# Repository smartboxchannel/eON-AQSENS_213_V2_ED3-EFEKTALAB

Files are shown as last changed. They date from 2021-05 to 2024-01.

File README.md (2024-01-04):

# EFEKTA-EINK213-AIR-QUALITY-SENSOR-NRF52840-V2-ED3

Wireless, battery-operated Mini air quality and weather station. Air quality, temperature, humidity, pressure, weather forecast. Designed on the nRF52833, nRF52840 wireless radio modules. The temperature, humidity and pressure sensor BME280, air quality sensor SGP40 is used The device is powered by CR2477 battery. Consumption when transmitting data is 8mA, in sleep mode is 35uA (see datasheet SGP40).

Телеграм чат DIY Devices - https://t.me/diy_devices

Продажа DIY Устройств - https://t.me/diydevmart

### You can buy a ready-made device by writing to the mail hello@efektalab.com

### Delivery is carried out worldwide.

### You can make your own pcb here - https://www.pcbway.com/setinvite.aspx?inviteid=550959

https://hackaday.io/project/180248-eon-indoor-air-quality-sensor
---

#### GDEH0213B72 (GDEH0213B73, Waveshare V2): https://ali.ski/05GbQ

(250x122,2.13inch E-Ink raw display panel Without PCB Communicate via SPI interface)

#### MS88SF3: https://ali.ski/I_UNg

(New FCC CE RoHs Certificated Compact (18.5×12.5×2mm) and Flexible ultra-low power wireless BLE 5.0 Module based on nRF52840 SoCs)

#### SGP40: https://ali.ski/3sbUP  |  https://ali.ski/9caWj

Video: 

More info at http://efektalab.com/eink213_ed3

---
## Ver. A

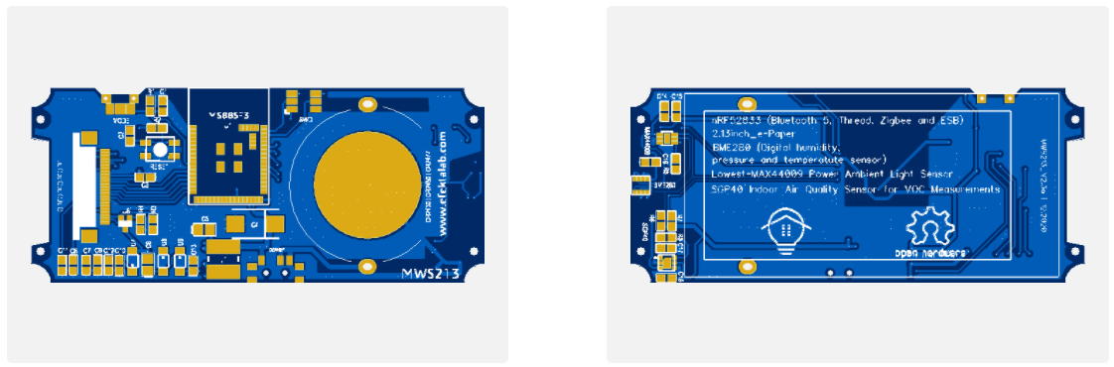
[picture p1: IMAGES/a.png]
 

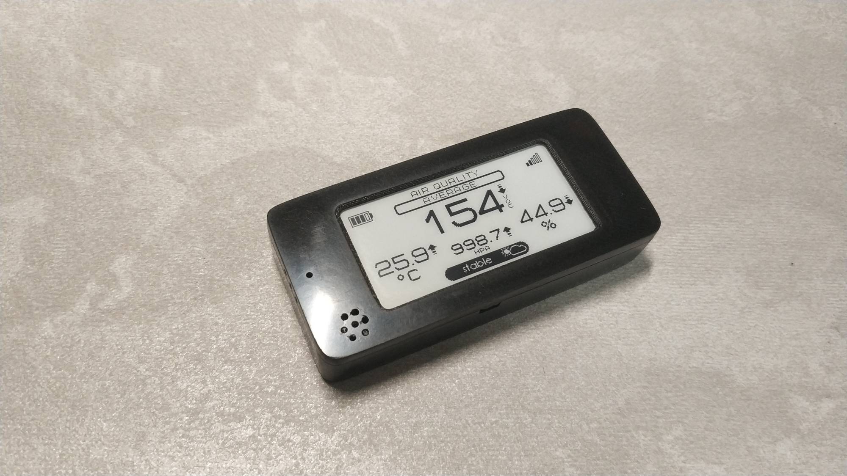
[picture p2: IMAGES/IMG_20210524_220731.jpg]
 

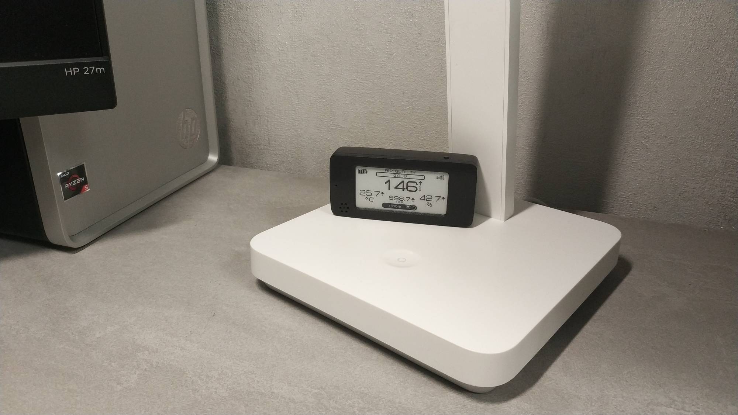
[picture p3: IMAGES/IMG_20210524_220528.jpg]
 

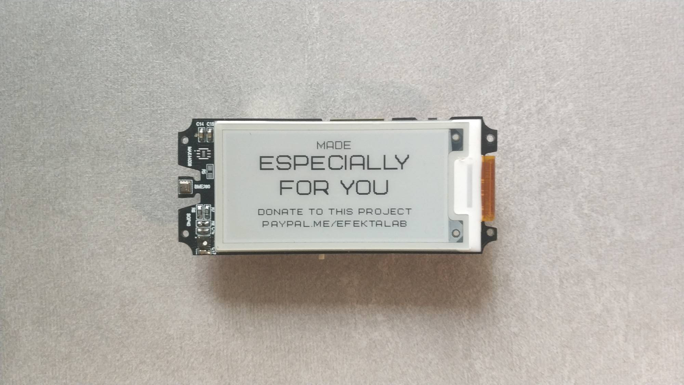
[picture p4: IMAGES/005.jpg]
 

---

EFEKTA EINK102 TEMP HUM MICRO SENSOR NRF52 licenses

---

### Instruction

#### First of all, I recommend installing the Arduino IDE portable (optional, but desirable)

https://www.arduino.cc/en/Guide/PortableIDE

#### 1. Install the latest arduino-nRF5 library (https://github.com/sandeepmistry/arduino-nRF5)

#### 2. Install the latest version of the MySensors library (https://github.com/mysensors/MySensors)

#### 3. Download the archive of this project to your computer

#### 4. Add support for devices of this project to the arduino-nRF5 library, the description is in the README.md file (https://github.com/smartboxchannel/EFEKTA-EINK213-TEMP-HUM-PRESS-SENSOR-NRF52840-V2/tree/master/for_sandeepmistry_nRF5/README.md)

#### 5. Add support for interrupts via gpiote, for this go to the ... packages \ sandeepmistry \ hardware \ nRF5 \ 0.7.0 \ cores \ nRF5 folder, and in the WInterrupts.c file, before the void GPIOTE_IRQHandler () function, add the line: \_\_attribute\_\_ ((weak ))

#### 6. Add the libraries in the archive () https://github.com/smartboxchannel/EFEKTA-EINK213-TEMP-HUM-PRESS-SENSOR-NRF52840-V2/tree/master/CODE/Arduino/libraries  of this project to the libraries folder on your computer ( path: ...\Documents\Arduino\libraries )

#### 7. Create an EINK213ED2 folder on your computer under the Arduino directory (Documents \ Arduino). Add the files of this project located in the Arduino section (https://github.com/smartboxchannel/EFEKTA-EINK213-TEMP-HUM-PRESS-SENSOR-NRF52840-V2/tree/master/CODE/Arduino) to the created EINK213ED2 folder

#### 8. Open the EINK213ED2.ino file in the Arduino IDE program, go to the aConfig.h tab and configure according to your board version and settings of your MySensors network.

#### 9. In the main menu of the Arduino IDE go to Tools-> Boards-> Nordic Semiconductors nRF5 Boards, in the list that opens, select the EFEKTA MWS213 V2 nRF52840 board. In the menu of the selected board, select the type of clock crystal (external), also select the Reset: Enable item.

#### 10. Click on the icon - check and then download

---

---

## Components (BOM):

SGP40: https://ali.ski/eZQog

MINEW MS88SF3 FCC CE RoHs Certificated wireless module nRF52840 SoCs - https://ali.ski/9LnWZ (1 pc - $7.75)

MAX44009EDT  - https://ali.ski/_PLrJ  (5 pcs - $9.3)
OR
MAX44009EDT  - https://ali.ski/bZoMnn  (1 pc - $1.9)

BME280 - https://ali.ski/wLEIir (2 pcs - $11.5)

Waveshare 250x122 2,13 - https://ali.ski/D4eOVU (1pc - $12.3)

FPC FFC 0.5mm connector socket 24 pin - https://ali.ski/lCBot0 (1 p - $0.77)

Cell Holder CR2450 - https://ali.ski/VdotsA (20 pcs - $3)

Micro Screws M1.4 3mm - https://ali.ski/gaFdO (100 pcs - $1)

Micro Screws M1.4 5mm - https://ali.ski/gaFdO (100 pcs - $1)

Micro SMD Tact Switch 2x4 2*4*3.5 - https://ali.ski/_D78Q (10 pcs - $1)

Neodymium magnet 15x3x3m - https://ali.ski/44p3R (10 pcs - $7)

Tantalum Capacitor 100UF 10V - https://ali.ski/Lx9iQd (10 pcs - $1,85)

Inductor Power Shielded Wirewound NR5040 5x5x4mm - https://ali.ski/iblu8q (50 pcs - $3)

Micro Button Tact Switch SMD 4Pin 3X4X2.5 - https://ali.ski/sGwFu (100 pcs - $1.7)

SMD Mini Toggle Slide Switch 7-Pin On/Off - https://ali.ski/xz9Yt (100 pcs - $3.2)

SI1308EDL - https://ali.ski/Q6Y12 (20 pcs - $5.3)
OR
Si1304BDL - https://ali.ski/938Klh (100 pcs - $15.5)

SMD Chip Multilayer Ceramic Capacitor 0603 1UF 25V - https://ali.ski/p3yr60 (100 pcs - $1.5)

SMD Chip Multilayer Ceramic Capacitor 0603 0.1UF 50V - https://ali.ski/p3yr60 (100 pcs - $1.5)

SMD Chip Multilayer Ceramic Capacitor 0805 4.7UF - https://ali.ski/iFXAc (100 pcs - $1.85)

MBR0530T1G - https://ali.ski/SJM7aK (100 pcs - $1.1)

SMD LED 0805 - https://ali.ski/wb6ZP (100 pcs - $2)

1% SMD resistor 0.47R 0603 - https://ali.ski/bX9HUg (100 pcs - $1.2)

1% SMD Resistor Kit Assorted Kit 1R-1M 0603 -  https://ali.ski/npItF (660 pcs - $1.45)

SUNLU PLA Carbon Fiber Premium 3D Printer Filament - https://ali.ski/bQkNR (1 pcs - $26.5)

405nm UV Resin For 3d Printer - https://ali.ski/sW0MUm (1 pcs - $18.5)

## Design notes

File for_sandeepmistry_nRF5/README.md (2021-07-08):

#### 1. Add lines from the file boards.txt to a file with the same name(boards.txt) located in the installed 'sandeepmistry' library. 

Path: ...\AppData\Local\Arduino15\packages\sandeepmistry\hardware\nRF5\0.7.0

#### 2. Replace the file platform.txt with a similar file from this repository 

Path: ...\AppData\Local\Arduino15\packages\sandeepmistry\hardware\nRF5\0.7.0

#### 3. Add the folder EFEKTA_MWS213_V2 with all the attached files to the /variants folder

Path: ...\AppData\Local\Arduino15\packages\sandeepmistry\hardware\nRF5\0.7.0\variants

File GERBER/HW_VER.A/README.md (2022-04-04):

Нou can make your own pcb here - https://www.pcbway.com/setinvite.aspx?inviteid=550959

pcb 1mm - https://www.pcbway.com/project/shareproject/eON_AQSENS_213_dab8c1e9.html

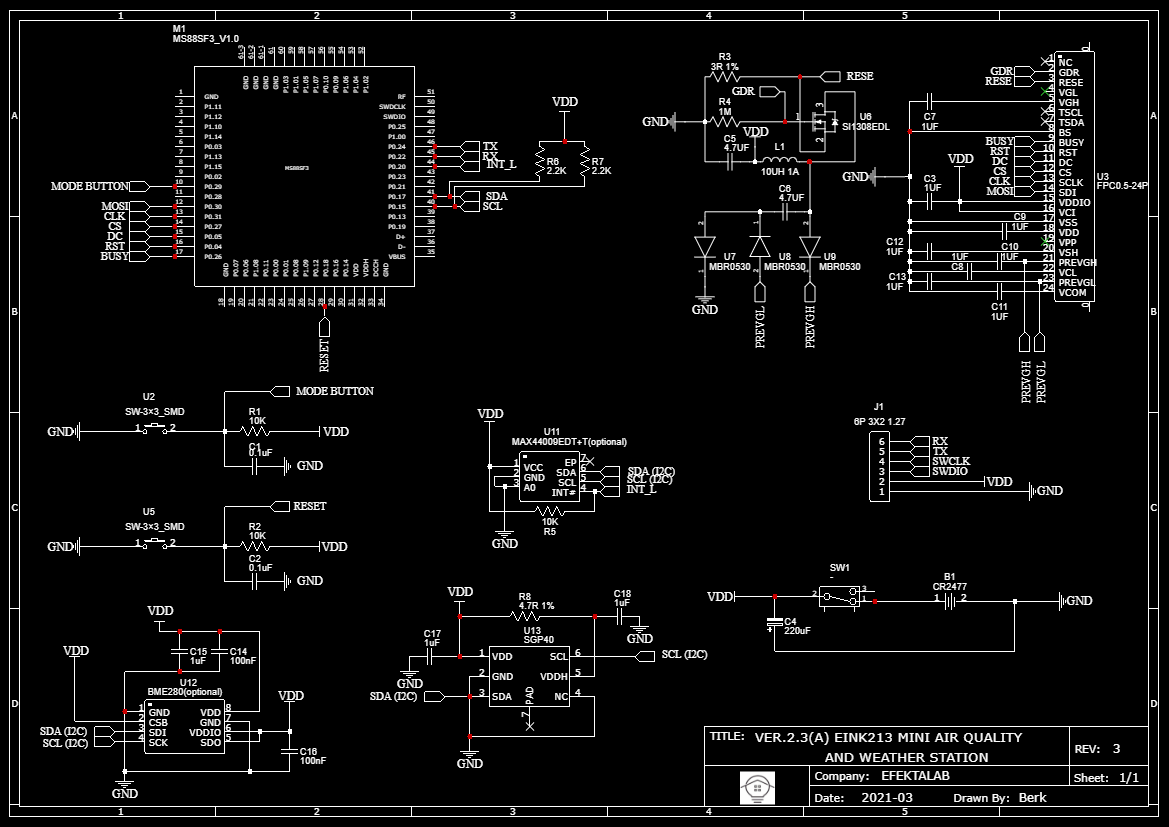
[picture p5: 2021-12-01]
SCHEME/aq_V2.3a _12.2020.png

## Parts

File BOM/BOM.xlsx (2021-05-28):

Comment | Designator | Footprint
100nF | C1,C2,C14,C15 | 0603_C | https://ali.ski/p3yr60
1uF | C3,C7,C8,C9,C10,C11,C12,C13,C15,C17,C18 | 0603_C | https://ali.ski/p3yr60
100uF | C4 | D_Tantal | https://ali.ski/Lx9iQd
4.7uF | C5,C6 | C0805 | https://ali.ski/iFXAc
6P | J1 | 6x1.27 | https://ali.ski/j2fO8
10uH\1A | L1 | CD54 | https://ali.ski/iblu8q
10KΩ | R1,R2,R5 | 0603_R | https://ali.ski/bX9HUg
3Ω\1% | R3 | 0603_R | https://ali.ski/bX9HUg
1MΩ | R4 | 0603_R | https://ali.ski/bX9HUg
2.2KΩ | R6,R7 | 0603_C | https://ali.ski/bX9HUg
4.7Ω\1% | R8 | 0603_R | https://ali.ski/bX9HUg
MS88SF3\MINEW | U1 | MS88SF3 | https://ali.ski/9LnWZ
BUTTON | U2 | but 2x4 2*4*3,5 | https://ali.ski/_D78Q
BAT HOLDER | U3 | CR2477 | https://ali.ski/VdotsA
FPC24 | U4 | FPC24 | https://ali.ski/lCBot0
BUTTON | U5 | B_3X4X2,5 | https://ali.ski/sGwFu
SI1308EDL | U6 | SC70 | https://ali.ski/Q6Y12
MBR0530 | U7,U8,U9 | SOD-123 | https://ali.ski/SJM7aK
POWER SWITCH | U10 | dsc0012 | https://ali.ski/xz9Yt
MAX44009 | U11 | 6 UTDFN-Opto | https://ali.ski/_PLr (https://ali.ski/_PLrJ)
BME280 | U12 | LGA | https://ali.ski/wLEIir
SGP40 | U13 | 6-pin DFN | https://ali.ski/eZQog
 | Waveshare 250x122 2,13 - https://ali.ski/D4eOVU
 | Micro Screws M1.4 3mm - https://ali.ski/gaFdO
 | Micro Screws M1.4 5mm - https://ali.ski/gaFdO
 | Neodymium magnet 15x3x3m - https://ali.ski/44p3R

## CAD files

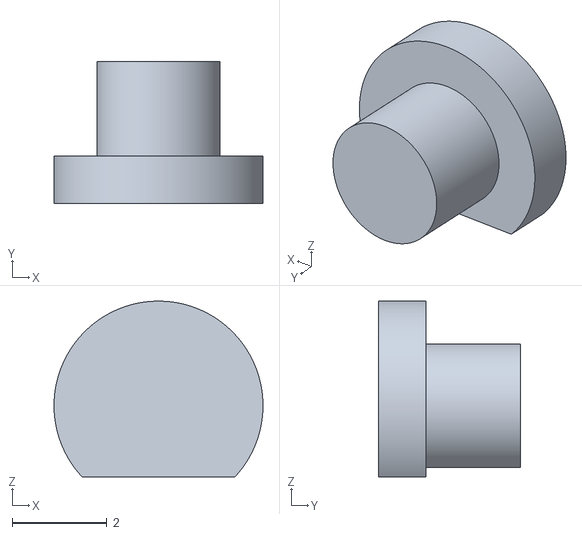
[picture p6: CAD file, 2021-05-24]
CASE 3D MODELS/BUTTON.STL
4.40 x 3.00 x 3.70

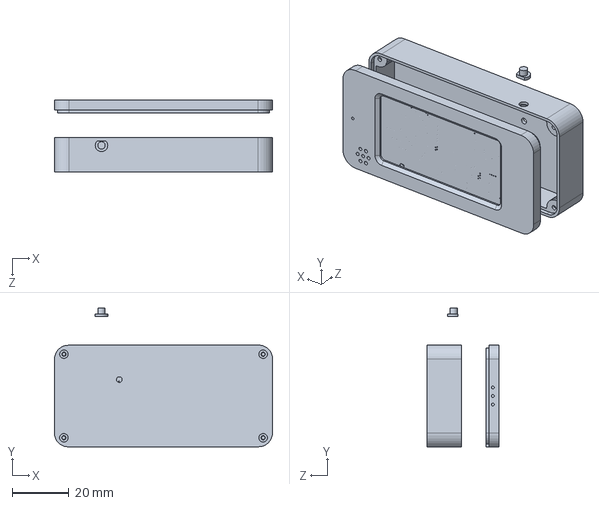
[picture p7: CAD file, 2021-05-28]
CASE 3D MODELS/SOURCE/AQ.SLDPRT
76.6 x 48.7 x 25.4 mm

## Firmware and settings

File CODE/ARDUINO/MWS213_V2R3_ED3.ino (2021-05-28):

// ###################   Mini air quality and wither station with electronic ink display 2.13 Inch | nRF52   ############### //
//                                                                                                                           //
//        @filename   :   MWS213_V2R3_ED3.ino                                                                                //
//        @brief en   :   Wireless, battery-operated air quality(VOC Sensor SGP40), temperature,humidity and pressure        //
//                        sensor(BME280) with electronic ink display(Good Display GDEH0213B72, GDEH0213B73, Waveshare V2).   //
//                        Works on SOC nRF52.                                                                                //
//        @brief ru   :   Беcпроводной, батарейный датчик качества воздуха (ЛОС сенсорс SGP40), температуры, влажности       //
//                        и давления(BME280) с дисплеем на электронных чернилах(Good Display GDEH0213B72, GDEH0213B73,       //
//                        Waveshare V2).                                                                                     //
//                        Работает на nRF52832, nRF52840.                                                                    //
//                                                                                                                           //
//        @author     :   Andrew Lamchenko aka Berk                                                                          //
//                                                                                                                           //
//        Copyright (C) 2021, EFEKTALAB                                                                                      //
//        Copyright (c) 2020, Sensirion AG                                                                                   //
//        Copyright (c) 2020, Bosch Sensortec GmbH. All rights reserved.                                                     //
//        Copyright (c) 2014-2015, Arduino LLC.  All right reserved.                                                         //
//        Copyright (c) 2016, Arduino Srl.  All right reserved.                                                              //
//        Copyright (c) 2017, Sensnology AB. All right reserved.                                                             //
//        Copyright (C) 2020, Waveshare                                                                                      //
//                                                                                                                           //
// ######################################################################################################################### //



#include "aConfig.h" //Edit this file for your sensor configuration


// ##############################################################################################################
// #                                                 DRIVERS & LIB                                              #
// ##############################################################################################################
#include "eink213_V2.h"
#include "imagedata.h"
#include "einkpaint.h"
#include "Adafruit_SGP40.h" // !!!Non-standard constants are used for the air quality algorithm!!!
#include <Adafruit_Sensor.h>
#include <Adafruit_BME280.h>
// ##############################################################################################################



// ##############################################################################################################
// #                                                   VARIABLES                                                #
// ##############################################################################################################
unsigned char image[4000];
Paint paint(image, 0, 0);
Epd epd;
#define SEALEVELPRESSURE_HPA (1013.25)
Adafruit_BME280 bme;
Adafruit_SGP40 sgp;

int32_t voc_index;
int32_t old_voc_index = -500;
int32_t voc_index_Threshold = 10;
uint16_t sraw;
int32_t temp_voc_index;

float last_tmp;
bool upTemp;
bool downTemp;

float last_hm;
bool upHum;
bool downHum;

float last_pr;
bool upPress;
bool downPress;

long last_aq;
bool upAq;
bool downAq;

bool mesColorSet;
#ifdef SEND_RESET_REASON
bool mesReset;
#endif
bool mesBatSet;
bool mesAq;
bool mesVolt;
bool mesLink;
bool mesForec;
bool mesBaro;
bool mesHum;
bool mesTemp;
bool mesInfo;
bool needPresent;
bool metric;
bool colorPrint;
bool opposite_colorPrint;
bool sendAfterResTask;
bool changeB = true;
bool changeC = true;
bool updateink1;
bool updateink2;
bool updateink3;
bool updateink4;
bool updateinkclear;
bool check;
bool chek_h = true;
bool flag_update_transport_param;
bool flag_sendRoute_parent;
bool flag_no_present;
bool flag_nogateway_mode;
bool flag_find_parent_process;
bool nosleep;
bool change;
bool Ack_FP;
bool tch;
bool hch;
bool bch;
bool vch;
bool pch;
bool fch;
bool ach;
bool lch;
bool configMode;
bool button_flag;
uint8_t lang;
uint8_t cpNom;
uint8_t cpCount;
uint8_t battSend;
uint8_t timeSend = 1;
uint8_t battery;
uint8_t old_battery;
uint8_t err_delivery_beat;
const uint16_t shortWait = 5;
int16_t temperatureInt;
int16_t humidityInt;
int16_t pressureInt;
int16_t pressure_mmInt;
uint16_t batteryVoltage;
uint16_t old_batteryVoltage;
const uint16_t minuteT = 60000;
uint16_t BATT_TIME;
uint16_t BATT_COUNT;
int16_t nRFRSSI;
int16_t old_nRFRSSI = 127;
int16_t myid;
int16_t mypar;
int16_t old_mypar = -1;
float temperatureSend;
float pressureSend;
float humiditySend;
float old_temperature;
float old_humidity;
float old_pressure;
float tempThreshold = 0.5; // порог сравнения в предыдущими показаниями температуры
float humThreshold = 2.5; // порог сравнения в предыдущими показаниями влажности
float pressThreshold = 1.0; // порог сравнения в предыдущими показаниями влажности
float batteryVoltageF;

uint32_t configMillis;
uint32_t previousMillis;
uint32_t SLEEP_TIME;
uint32_t stopTimer;
uint32_t startTimer;
uint32_t PRECISION_TIME_WDT;
const uint32_t SLEEP_TIME_WDT = 3000;
uint32_t sleepTimeCount;
const uint8_t fastView = 5;
uint8_t checkFast;
// ##############################################################################################################



// ##############################################################################################################
// #                                                   MYSENSORS                                                #
// ##############################################################################################################
int16_t mtwr;
#define MY_TRANSPORT_WAIT_READY_MS (mtwr)
#include <MySensors.h>
#define TEMP_CHILD_ID 0
#define HUM_CHILD_ID 1
#define BARO_CHILD_ID 2
#define FORECAST_CHILD_ID 3
#define AQ_CHILD_ID 4
#define SIGNAL_Q_ID 100
#define BATTERY_VOLTAGE_ID 101
#define SET_BATT_SEND_ID 103
#define SET_COLOR_ID 104
#ifdef SEND_RESET_REASON
#define RESET_REASON_ID 105
#endif
MyMessage sqMsg(SIGNAL_Q_ID, V_VAR1);
MyMessage bvMsg(BATTERY_VOLTAGE_ID, V_VAR1);
// ##############################################################################################################


// ##############################################################################################################
// #                                                 FORECAST                                                   #
// ##############################################################################################################
#define CONVERSION_FACTOR (1.0/10.0)
const char *weather[] = { "stable", "sunny", "cloudy", "unstable", "thunderstorm", "unknown" };
enum FORECAST
{
  STABLE = 0,                     // "Stable Weather Pattern"
  SUNNY = 1,                      // "Slowly rising Good Weather", "Clear/Sunny "
  CLOUDY = 2,                     // "Slowly falling L-Pressure ", "Cloudy/Rain "
  UNSTABLE = 3,                   // "Quickly rising H-Press",     "Not Stable"
  THUNDERSTORM = 4,               // "Quickly falling L-Press",    "Thunderstorm"
  UNKNOWN = 5                     // "Unknown (More Time needed)
};
int16_t forecast;
int16_t  old_forecast = -1;
const int LAST_SAMPLES_COUNT = 5;
float lastPressureSamples[LAST_SAMPLES_COUNT];
int minuteCount = 0;
bool firstRound = true;
float pressureAvg;
float pressureAvg2;
float dP_dt;
// ##############################################################################################################


// ##############################################################################################################
// #                                                 INTERRUPTS                                                 #
// ##############################################################################################################
uint32_t PIN_BUTTON_MASK;
volatile byte buttIntStatus = 0;
#define APP_GPIOTE_MAX_USERS 1
extern "C" {
#include "app_gpiote.h"
#include "nrf_gpio.h"
}
static app_gpiote_user_id_t m_gpiote_user_id;
// ##############################################################################################################


void preHwInit() {
  pinMode(PIN_BUTTON, INPUT);
}

void before() {

  // ##############################################################################################################
  // #                                                   CONFIG MCU                                               #
  // ##############################################################################################################
  NRF_POWER->DCDCEN = 1;
  NRF_SAADC ->ENABLE = 0;
  NRF_PWM0  ->ENABLE = 0;
  NRF_NFCT->TASKS_DISABLE = 1;
  NRF_NVMC->CONFIG = 1;
  NRF_UICR->NFCPINS = 0;
  NRF_NVMC->CONFIG = 0;
  NRF_PWM1  ->ENABLE = 0;
  NRF_PWM2  ->ENABLE = 0;
  NRF_TWIM1 ->ENABLE = 0;
  NRF_TWIS1 ->ENABLE = 0;
#ifndef MY_DEBUG
  NRF_UART0->ENABLE = 0;
#endif


  // ##############################################################################################################
  // #                                                  INIT HAPPY MODE                                           #
  // ##############################################################################################################
  happy_init();


  // ##############################################################################################################
  // #                                                    CONFIG PROG                                             #
  // ##############################################################################################################
  battSend = loadState(103);  // Saving in memory the interval of sending data about battery charge and signal quality,
  // maximized 24 hours, if 0, the sending does not do, only updates the info on the screen
  if (battSend > 24) {
    battSend = 6;
    saveState(103, battSend);
  }
  //battSend = 1; // for the test, 1 hour

  if (loadState(104) > 1) {
    saveState(104, 0);
  }
  colorChange(loadState(104));
  //colorChange(true); // for the test, true || false

  timeConf();
  delay(500);

  // ##############################################################################################################
  // #                                                     EINK INIT                                              #
  // ##############################################################################################################
  displayStart();
}
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
void loop() {
  if (flag_update_transport_param == true) {
    update_Happy_transport();
  }
  if (flag_sendRoute_parent == true) {
    present_only_parent();
  }
  if (isTransportReady() == true) {
    if (flag_find_parent_process == true) {
      find_parent_process();
    }
    if (flag_nogateway_mode == false) {
      if (configMode == false) {
        if (buttIntStatus == PIN_BUTTON) {
          if (digitalRead(PIN_BUTTON) == 0 && button_flag == false) {
            button_flag = true;
            previousMillis = millis();
          }
          if (digitalRead(PIN_BUTTON) == 0 && button_flag == true) {
            if ((millis() - previousMillis > 0) && (millis() - previousMillis <= 3000)) {
              if (updateink1 == false) {
                einkZeropush();
                updateink1 = true;
              }
            }
            if ((millis() - previousMillis > 3000) && (millis() - previousMillis <= 4000)) {
              if (updateinkclear == false) {
                epd.Clear(colorPrint, PART);
                updateinkclear = true;
              }
            }
            if ((millis() - previousMillis > 4000) && (millis() - previousMillis <= 7000)) {
              if (updateink2 == false) {
                einkOnepush();
                updateink2 = true;
                updateinkclear = false;
              }
            }
            if ((millis() - previousMillis > 7000) && (millis() - previousMillis <= 8000)) {
              if (updateinkclear == false) {
                epd.Clear(colorPrint, PART);
                updateinkclear = true;
              }
            }
            if ((millis() - previousMillis > 8000) && (millis() - previousMillis <= 11000)) {
              if (updateink3 == false) {
                einkOnePluspush();
                updateink3 = true;
                updateinkclear = false;
              }
            }
            if ((millis() - previousMillis > 11000) && (millis() - previousMillis <= 12000)) {
              if (updateinkclear == false) {
                epd.Clear(colorPrint, PART);
                updateinkclear = true;
              }
            }
            if ((millis() - previousMillis > 12000) && (millis() - previousMillis <= 15000)) {
              if (updateink4 == false) {
                einkTwopush();
                updateink4 = true;
                updateinkclear = false;
              }
            }
            if (millis() - previousMillis > 15000) {
              if (updateinkclear == false) {
                epd.Clear(colorPrint, PART);
                updateinkclear = true;
                buttIntStatus = 0;
                change = true;
                sleepTimeCount = SLEEP_TIME;
              }
            }
          }

          if (digitalRead(PIN_BUTTON) == 1 && button_flag == true) {
            if (millis() - previousMillis <= 3000 && button_flag == true)
            {
              einkPushEnd();
              reseteinkset();
              if (colorPrint == true) {
                colorPrint = false;
                colorChange(colorPrint);
              } else {
                colorPrint = true;
                colorChange(colorPrint);
              }
              sleepTimeCount = 0;
              readSensor();
              change = false;
              sendData();
              wait(20);
              eInkUpdate();
              change = false;
              button_flag = false;
              buttIntStatus = 0;
              nosleep = false;
            }
            if ((millis() - previousMillis > 4000) && (millis() - previousMillis <= 7000) && button_flag == true)
            {
              einkPushEnd();
              reseteinkset();
              transportReInitialise();
              wait(shortWait);
              resetBeforePresent();
              presentation();
              transportDisable();
              wait(shortWait);
              sleepTimeCount = 0;
              readSensor();
              change = false;
              sendData();
              wait(20);
              eInkUpdate();
              change = false;
              button_flag = false;
              buttIntStatus = 0;
              nosleep = false;
            }
            if ((millis() - previousMillis > 8000) && (millis() - previousMillis <= 11000) && button_flag == true)
            {
              einkPushEnd();
              reseteinkset();
              configMode = true;
              button_flag = false;
              buttIntStatus = 0;
              transportReInitialise();
              wait(shortWait);
              NRF5_ESB_startListening();
              wait(shortWait * 5);
              configMillis = millis();
            }
            if ((millis() - previousMillis > 12000) && (millis() - previousMillis <= 15000) && button_flag == true)
            {
              einkPushEnd();
              wait(1500);
              new_device();
            }
            if (((millis() - previousMillis > 3000) && (millis() - previousMillis <= 4000) && button_flag == true) || ((millis() - previousMillis > 7000) && (millis() - previousMillis <= 8000) && button_flag == true) || ((millis() - previousMillis > 11000) && (millis() - previousMillis <= 12000) && button_flag == true) || ((millis() - previousMillis > 15000) && button_flag == true))
            {
              wdt_nrfReset();
              reseteinkset();
              sleepTimeCount = 0;
              readSensor();
              change = false;
              sendData();
              wait(20);
              eInkUpdate();
              change = false;
              button_flag = false;
              buttIntStatus = 0;
              nosleep = false;
            }
          }
        } else {
          sleepTimeCount++;
          if (sleepTimeCount >= SLEEP_TIME) {
            sleepTimeCount = 0;

            readSensor();
            if (change == true) {
              sendData();
              wait(20);
              eInkUpdate();
              change = false;
            }
            nosleep = false;
          } else {
            readSGP();
            if (change == true) {
              sendData();
              wait(100);
              eInkUpdate();
              change = false;
            }
            nosleep = false;
          }
        }
      } else {
        if (millis() - configMillis > 20000) {
          transportDisable(); // вроде потому что один фиг сразу в сон? ....не все таки раскоментить потому что сон не сразу а сначала обновление экрана
          configMode = false;
          sleepTimeCount = 0;
          readSensor();
          change = false;
          sendData();
          wait(20);
          eInkUpdate();
          change = false;
          button_flag = false;
          buttIntStatus = 0;
          nosleep = false;
        }
        wdt_nrfReset();
      }
    } else {
      if (buttIntStatus == PIN_BUTTON) {
        if (digitalRead(PIN_BUTTON) == 0 && button_flag == 0) {
          button_flag = 1;
          previousMillis = millis();
        }
        if (digitalRead(PIN_BUTTON) == 0 && button_flag == 1) {
          if ((millis() - previousMillis > 0) && (millis() - previousMillis <= 3000)) {
            if (updateink1 == false) {
              einkZeropush();
              updateink1 = true;
            }
          }
          if ((millis() - previousMillis > 3000) && (millis() - previousMillis <= 4000)) {
            if (updateinkclear == false) {
              epd.Clear(colorPrint, PART);
              updateinkclear = true;
            }
          }
          if ((millis() - previousMillis > 4000) && (millis() - previousMillis <= 7000)) {
            if (updateink2 == false) {
              einkOnepush();
              updateink2 = true;
              updateinkclear = false;
            }
          }
          if ((millis() - previousMillis > 7000) && (millis() - previousMillis <= 8000)) {
            if (updateinkclear == false) {
              epd.Clear(colorPrint, PART);
              updateinkclear = true;
            }
          }
          if ((millis() - previousMillis > 8000) && (millis() - previousMillis <= 11000)) {
            if (updateink4 == false) {
              einkTwopush();
              updateink4 = true;
              updateinkclear = false;
            }
          }
          if (millis() - previousMillis > 11000) {
            if (updateinkclear == false) {
              epd.Clear(colorPrint, PART);
              updateinkclear = true;
              buttIntStatus = 0;
              change = true;
              sleepTimeCount = SLEEP_TIME;
            }
          }
        }
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

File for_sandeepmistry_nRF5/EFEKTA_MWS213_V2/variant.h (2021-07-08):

/*
  Copyright (c) 2014-2015 Arduino LLC.  All right reserved.
  Copyright (c) 2016 Sandeep Mistry All right reserved.
  This library is free software; you can redistribute it and/or
  modify it under the terms of the GNU Lesser General Public
  License as published by the Free Software Foundation; either
  version 2.1 of the License, or (at your option) any later version.
  This library is distributed in the hope that it will be useful,
  but WITHOUT ANY WARRANTY; without even the implied warranty of
  MERCHANTABILITY or FITNESS FOR A PARTICULAR PURPOSE.
  See the GNU Lesser General Public License for more details.
  You should have received a copy of the GNU Lesser General Public
  License along with this library; if not, write to the Free Software
  Foundation, Inc., 51 Franklin St, Fifth Floor, Boston, MA  02110-1301  USA
*/

#ifndef _VARIANT_EFEKTA_MWS213_V2_
#define _VARIANT_EFEKTA_MWS213_V2_

#include "nrf.h"
#include "nrf_peripherals.h"

/** Master clock frequency */
#if defined(NRF52_SERIES)
#define VARIANT_MCK       (64000000ul)
#else
#define VARIANT_MCK       (16000000ul)
#endif

/*----------------------------------------------------------------------------
 *        Headers
 *----------------------------------------------------------------------------*/

#include "WVariant.h"

#ifdef __cplusplus
extern "C"
{
#endif // __cplusplus

// Number of pins defined in PinDescription array
#if GPIO_COUNT == 1
#define PINS_COUNT           (32u)
#define NUM_DIGITAL_PINS     (32u)
#elif GPIO_COUNT == 2
#define PINS_COUNT           (64u)
#define NUM_DIGITAL_PINS     (64u)
#else
#error "Unsupported GPIO_COUNT"
#endif
#define NUM_ANALOG_INPUTS    (8u)
#define NUM_ANALOG_OUTPUTS   (8u)

// LEDs
#define PIN_LED              (6) // P0.06
#define LED_BUILTIN          (PIN_LED)
#define BLUE_LED             (PIN_LED)

#define PIN_BUTTON           (29)

#define RST_PIN              (4)
#define DC_PIN               (5)
#define CS_PIN               (27)
#define BUSY_PIN             (26)

/*
 * Analog pins
 */
#define PIN_A0               (2) // P0.02
#define PIN_A1               (3) // P0.03
#define PIN_A2               (4) // P0.04
#define PIN_A3               (5) // P0.05
#define PIN_A4               (28)// P0.28
#define PIN_A5               (29)// P0.29
#define PIN_A6               (30)// P0.30
#define PIN_A7               (31)// P0.31

static const uint8_t A0  = PIN_A0 ;
static const uint8_t A1  = PIN_A1 ;
static const uint8_t A2  = PIN_A2 ;
static const uint8_t A3  = PIN_A3 ;
static const uint8_t A4  = PIN_A4 ;
static const uint8_t A5  = PIN_A5 ;
static const uint8_t A6  = PIN_A6;
static const uint8_t A7  = PIN_A7;
#if defined(NRF52_SERIES)
#define ADC_RESOLUTION    14
#else
#define ADC_RESOLUTION    10
#endif

/*
 * Serial interfaces
 */
// Serial
#define PIN_SERIAL_RX       (22) // P0.22
#define PIN_SERIAL_TX       (24) // P0.24

/*
 * SPI Interfaces
 */
#define SPI_INTERFACES_COUNT 1

#define PIN_SPI_MISO         (2) // P0.28 not conected
#define PIN_SPI_MOSI         (30) // P0.30
#define PIN_SPI_SCK          (31) // P0.31

static const uint8_t SS   = CS_PIN ;  // P0.27
static const uint8_t MOSI = PIN_SPI_MOSI ;
static const uint8_t MISO = PIN_SPI_MISO ;
static const uint8_t SCK  = PIN_SPI_SCK ;

/*
 * Wire Interfaces
 */
#define WIRE_INTERFACES_COUNT 1

#define PIN_WIRE_SDA         (17u) // P0.17
#define PIN_WIRE_SCL         (15u) // P0.15

static const uint8_t SDA = PIN_WIRE_SDA;
static const uint8_t SCL = PIN_WIRE_SCL;

#ifdef __cplusplus
}
#endif

#endif

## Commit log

2021-05-09 HW Ver. A
    [BoardOutline.gbr, Bottom.gbr, BottomAssy.gbr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]
2021-05-28 V 0.96
    fixed, re-updating the display after actions with a custom button
    [MWS213_V2R3_ED3.ino]
2021-06-22 cybersonner_fix
    fix error in connecting capacitors C14, C15
2021-12-01 error in the circuit, si1308
